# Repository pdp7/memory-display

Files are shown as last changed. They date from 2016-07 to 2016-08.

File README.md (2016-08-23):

## OSH Park shared project
* [SHARP memory display and Teensy LC](https://oshpark.com/projects/4Hbq9Awy)

## Bill of Materials
* [SHARP Memory Display Breakout - 1.3" 96x96 Silver Monochrome](https://www.adafruit.com/product/1393)
* [Teensy LC - OSH Park Edition](http://store.oshpark.com/products/teensy-lc)
* [Adafruit BME280 sensor *(Temp/Hum/Press)*](https://www.adafruit.com/product/2652)

## Video
* [Short demo](https://www.youtube.com/watch?v=esPlImZcRdI)
* [Full demo](https://www.youtube.com/watch?v=OchR3nb700U)

## Photos
* [Google+ gallery](https://plus.google.com/photos/+DrewFustini/albums/6319926590582577217)
* [images gallery](https://github.com/pdp7/memory-display/tree/master/images)
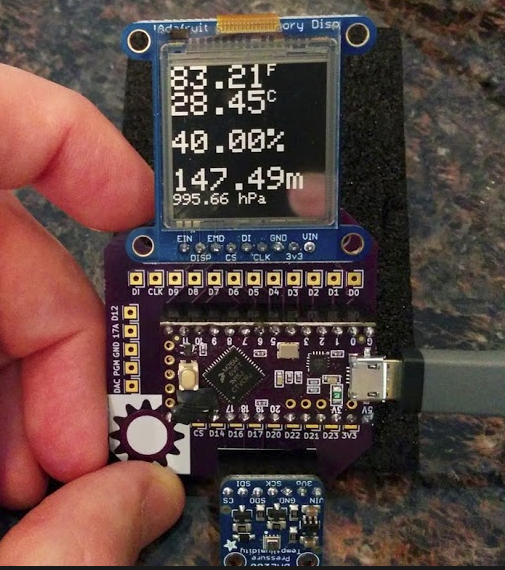
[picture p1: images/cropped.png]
photo of board
* 

## License
This project released under the CERN Open Hardware v1.2 License

**Note:** `memory-display.ino` based on library code and example code from [Adafruit Industries](http://adafruit.com/)

## Contact
* Drew Fustini &lt;drew@oshpark.com&gt;

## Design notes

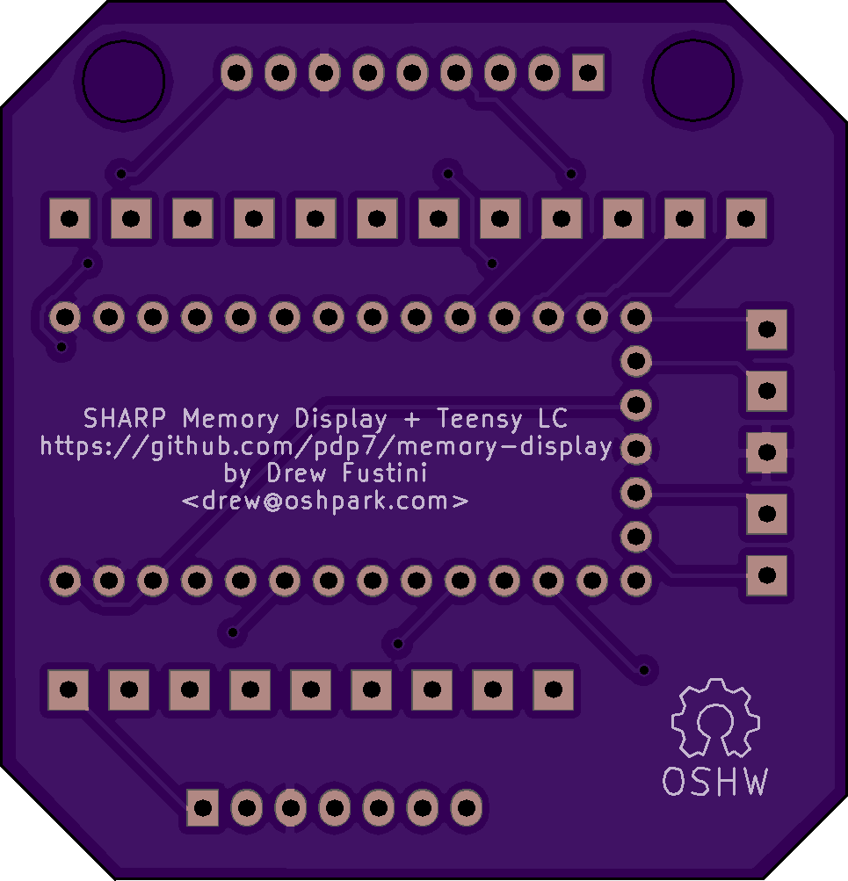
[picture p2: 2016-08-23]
images/back-pcb-preview.png

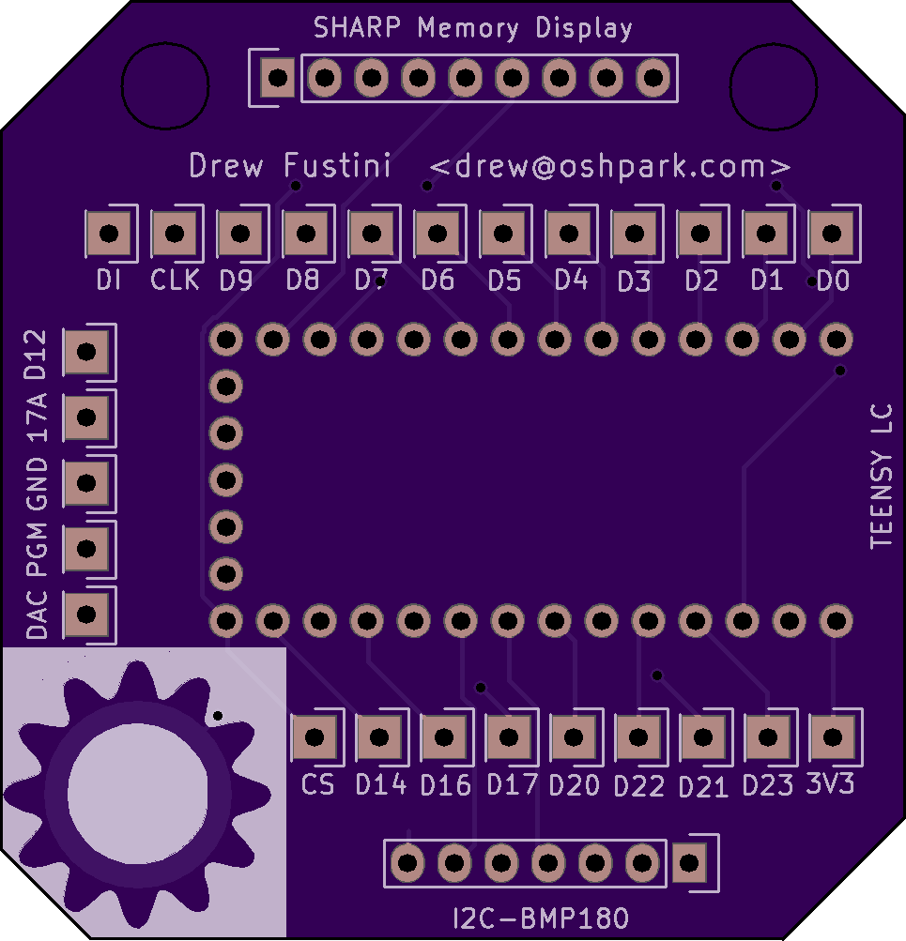
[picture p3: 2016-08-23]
images/front-pcb-preview.png

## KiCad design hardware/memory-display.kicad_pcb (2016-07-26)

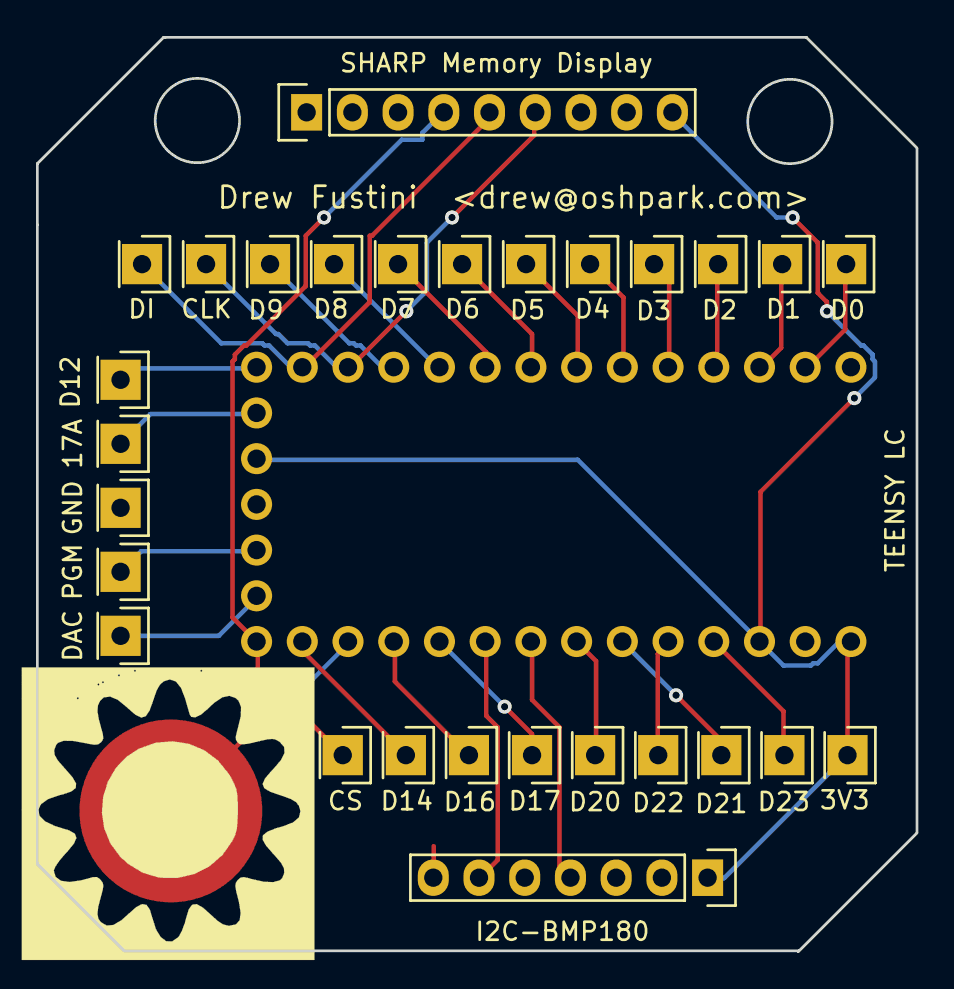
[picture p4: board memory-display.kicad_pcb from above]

Board: 2 copper layers, 48.9 x 50.8 mm, 30 parts (0 on the bottom side), 29 nets.

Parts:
3V3: 3v3; CONN-HEADER-STRAIGHT-P2.54MM-1x01
17A: 17A; CONN-HEADER-STRAIGHT-P2.54MM-1x01
CAP15: CAP15; CAPSENSE-CIRCLE-D10MM
CLK: CLK; CONN-HEADER-STRAIGHT-P2.54MM-1x01
CS: CS; CONN-HEADER-STRAIGHT-P2.54MM-1x01
D0: D0; CONN-HEADER-STRAIGHT-P2.54MM-1x01
D1: D1; CONN-HEADER-STRAIGHT-P2.54MM-1x01
D2: D2; CONN-HEADER-STRAIGHT-P2.54MM-1x01
D3: D3; CONN-HEADER-STRAIGHT-P2.54MM-1x01
D4: D4; CONN-HEADER-STRAIGHT-P2.54MM-1x01
D5: D5; CONN-HEADER-STRAIGHT-P2.54MM-1x01
D6: D6; CONN-HEADER-STRAIGHT-P2.54MM-1x01
D7: D7; CONN-HEADER-STRAIGHT-P2.54MM-1x01
D8: D8; CONN-HEADER-STRAIGHT-P2.54MM-1x01
D9: D9; CONN-HEADER-STRAIGHT-P2.54MM-1x01
D12: D12; CONN-HEADER-STRAIGHT-P2.54MM-1x01
D14: D14; CONN-HEADER-STRAIGHT-P2.54MM-1x01
D16: D16; CONN-HEADER-STRAIGHT-P2.54MM-1x01
D17: D17; CONN-HEADER-STRAIGHT-P2.54MM-1x01
D20: D20; CONN-HEADER-STRAIGHT-P2.54MM-1x01
D21: D21; CONN-HEADER-STRAIGHT-P2.54MM-1x01
D22: D22; CONN-HEADER-STRAIGHT-P2.54MM-1x01
D23: D23; CONN-HEADER-STRAIGHT-P2.54MM-1x01
DAC: DAC; CONN-HEADER-STRAIGHT-P2.54MM-1x01
DI: DI; CONN-HEADER-STRAIGHT-P2.54MM-1x01
GND: PGM; CONN-HEADER-STRAIGHT-P2.54MM-1x01
I2C-BMP180: I2C-BMP180; Pin_Header_Straight_1x07
J1: TEENSY-LC
PGM: PGM; CONN-HEADER-STRAIGHT-P2.54MM-1x01
SHARP Memory Display: SHARP-MEM-DISP; Pin_Header_Straight_1x09

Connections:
+3V3: 3V3.1, I2C-BMP180.1, J1.3V1, J1.3V2, J1.VIN, SHARP Memory Display.9
/CLK: CLK.1, J1.10, SHARP Memory Display.6
/CS: CS.1, I2C-BMP180.7, J1.13, SHARP Memory Display.4
/D0: D0.1, J1.0
/D1: D1.1, J1.1
/D2: D2.1, J1.2
/D3: D3.1, J1.3
/D4: D4.1, J1.4
/D5: D5.1, J1.5
/D6: D6.1, J1.6
/D7: D7.1, J1.7
/D8: D8.1, J1.8
/D9: D9.1, J1.9
/D11: DI.1, J1.11, SHARP Memory Display.5
/D12: D12.1, J1.12
/D14: D14.1, J1.14
/D15: CAP15.1, J1.15
/D16: D16.1, J1.16
/D17: D17.1, J1.17
/D17(VIN): 17A.1, J1.17A
/D18: I2C-BMP180.6, J1.18
/D19: I2C-BMP180.4, J1.19
/D20: D20.1, J1.20
/D21: D21.1, J1.21
/D22: D22.1, J1.22
/D23: D23.1, J1.23
/DAC: DAC.1, J1.DAC
/PROG: J1.PGM, PGM.1
GND: GND.1, I2C-BMP180.3, J1.G1, J1.G2, J1.G3, SHARP Memory Display.7

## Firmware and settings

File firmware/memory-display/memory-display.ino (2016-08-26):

/*********************************************************************
  Based on library code and example code from Adafruit Industries:

    example sketch for our Monochrome SHARP Memory Displays
      http://www.adafruit.com/products/1393
    library for the BME280 humidity, temperature & pressure sensor
      http://www.adafruit.com/products/2650

  NOTE from Adafruit:
  Adafruit invests time and resources providing this open source code,
  please support Adafruit and open-source hardware by purchasing
  products from Adafruit!

  LICENSE for Adafruit code:
  Written by Limor Fried & Kevin Townsend for Adafruit Industries.
  BSD license, all text above must be included in any redistribution
*********************************************************************/

#include <Wire.h>
#include <SPI.h>
#include <Adafruit_GFX.h>
#include <Adafruit_SharpMem.h>
#include <Adafruit_Sensor.h>
#include <Adafruit_BME280.h>

#define SCK 10
#define MOSI 11
#define SS 13

#define BLACK 0
#define WHITE 1

#define BME_SCK 13
#define BME_MISO 12
#define BME_MOSI 11
#define BME_CS 10

#define SEALEVELPRESSURE_HPA (1013.25)

#define REFRESH_DELAY_MS 2000
#define TOUCH_DELTA_THRESHOLD 500

Adafruit_SharpMem display(SCK, MOSI, SS);
Adafruit_BME280 bme; // I2C

bool inverted = false; // state of display, black on white is default
bool touch_state = false; // state of cap touch button
bool old_touch_state = false; // previous state of cap touch button
int old_reading = 0; // previous cap touch pin reading

// true when display transistioned in previous iteration
bool recent_transition = false;

void setup() {

  display.begin();
  display.clearDisplay();
  display.setTextColor(BLACK, WHITE);
  display.println("SHARP Mem LCD");
  display.refresh();
  delay(1000);
  display.clearDisplay();

  Serial.begin(9600);
  Serial.println(F("BME280 test"));

  if (!bme.begin()) {
    Serial.println("Could not find a valid BME280 sensor, check wiring!");
    while (1);
  }

  display.refresh();
  delay(100);

  old_reading = touchRead(A1);
}

void loop() {

  float temp_c = bme.readTemperature();
  float temp_f = (((temp_c * 9.0) / 5.0 ) + 32.0 );
  float humidity = bme.readHumidity();
  float hpa = bme.readPressure() / 100.0F;
  float alt = bme.readAltitude(SEALEVELPRESSURE_HPA);

  if (inverted) {
    display.fillRect(0, 0, display.width(), display.height(), 0);
    display.setTextColor(WHITE, BLACK);
  } else {
    display.setTextColor(BLACK, WHITE);
  }

  display.setCursor(0, 0);

  display.setTextSize(2);
  display.print( temp_f );
  display.setTextSize(1);
  display.print("F ");
  display.setTextSize(2);
  display.println();

  display.setTextSize(2);
  display.print( temp_c );
  display.setTextSize(1);
  display.print("C");
  display.setTextSize(2);
  display.println();

  display.setTextSize(1);
  display.println();

  display.setTextSize(2);
  display.print(humidity);
  display.println("%");

  display.setTextSize(1);
  display.println();

  display.setTextSize(2);
  display.print(alt);
  display.print("m");
  display.setTextSize(2);
  display.println();

  display.setTextSize(1);

  display.print( hpa );
  display.print(" hPa");

  int reading = touchRead(A1);
  int delta = abs(reading - old_reading);

  /*
  display.print(delta);
  display.print("=|");
  display.print(old_reading);
  display.print("-");
  display.print(reading);
  display.print("|");
  */
  
  display.refresh();
  delay(REFRESH_DELAY_MS);

  if (delta > TOUCH_DELTA_THRESHOLD) {
    touch_state = true;
  } else {
    touch_state = false;
  }
  
  // change display state on button transistion
  if ((touch_state != old_touch_state) && (!recent_transition)) {
      if (inverted) {
        inverted = false;
      } else {
        inverted = true;
      }
      display.clearDisplay();
      recent_transition = true;
  } else {
    recent_transition = false;
  }

  /*
  Serial.print("old_touch_state=");
  Serial.print(old_touch_state);
  Serial.print("\ttouch_state=");
  Serial.print(touch_state);
  Serial.print("\tinverted=");
  Serial.print(inverted);
  Serial.print("\trecent_transition=");
  Serial.print(recent_transition);
  Serial.println();
  */
  
  // current touch button state now becomes the old state
  old_touch_state = touch_state;
}

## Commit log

2016-07-24 add BoM
    [memory-display.kicad_pcb, memory-display.sch]
2016-07-25 finished schematic and start layout
    [memory-display.kicad_pcb, memory-display.sch]
2016-07-26 finish layout
    [memory-display.kicad_pcb, memory-display.sch]
2016-08-16 refactor directory structure and add Arduino code
    [memory-display.kicad_pcb, memory-display.sch]
2016-08-17 read cap touch button
2016-08-23 invert display every 1 second
    [memory-display.ino]
2016-08-26 toggle display mode when button pressed
2016-09-09 switch from BME280 sensor to BMP280
    I do not have an Adafruit BME280 sensor breakout board
    to use for this project at the moment. I've switched
    to the BMP280 which has the same pinout but does not
    have humidity sensor. I've changed the display code
    to display just temperature, altitude and pressure.
2016-09-09 Revert "switch from BME280 sensor to BMP280"
    This reverts commit cdd505683a4165569ee07a68f52abad231dc8b78.
    bmp280 branch should be used instead of master
    [memory-display.ino]

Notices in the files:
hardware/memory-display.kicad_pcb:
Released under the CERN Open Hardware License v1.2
